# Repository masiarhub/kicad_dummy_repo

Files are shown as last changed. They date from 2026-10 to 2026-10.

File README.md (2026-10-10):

<p align="center" width="100%">
  
</p>

<h1 align="center">Board Name</h1>

<p align="center" width="100%">
  <a href="https://github.com/masiarhub/kicad_dummy_repo/actions/workflows/ci.yaml">
    
  </a>
</p>

<p align="center" width="100%">
    
</p>

***

<p align="center">
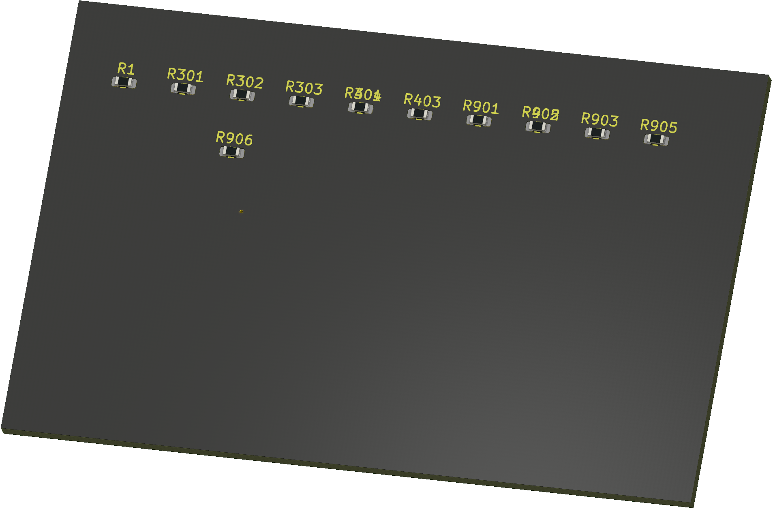
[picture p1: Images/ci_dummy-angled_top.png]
3D Top Angled
  
&nbsp; &nbsp; &nbsp; &nbsp;
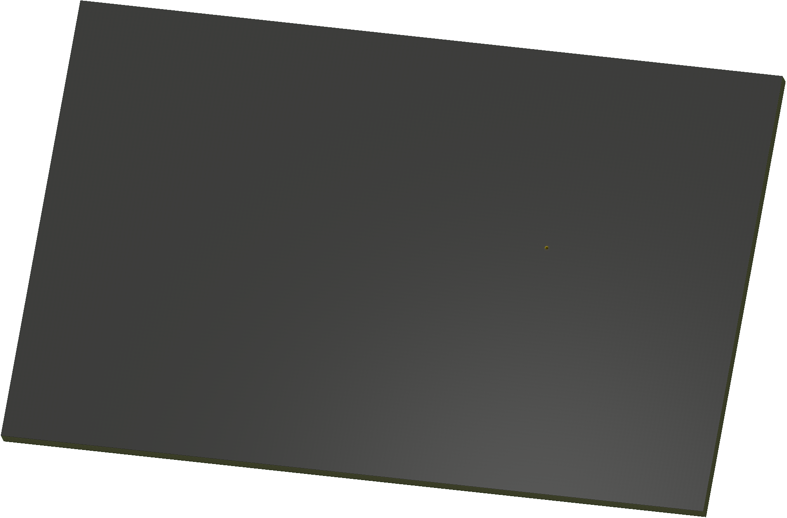
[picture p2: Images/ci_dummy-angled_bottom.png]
3D Bottom Angled
  
</p>

***

## SPECIFICATIONS

| Parameter | Value | 
| --- | --- |
| Dimensions | 70.0 × 45.0 mm |

***

## DIRECTORY STRUCTURE

    .
    ├─ Computations       # Misc calculations
    ├─ HTML               # HTML files for generated webpage
    ├─ Images             # Pictures and renders
    │
    ├─ kibot_resources    # External resources for KiBot
    │  ├─ colors          # Color theme for KiCad
    │  ├─ fonts           # Fonts used in the project
    │  ├─ scripts         # External scripts used with KiBot
    │  └─ templates       # Templates for KiBot generated reports
    │
    ├─ kibot_yaml         # KiBot YAML config files
    ├─ KiRI               # KiRI (PCB diff viewer) files
    │
    ├─ lib                # KiCad footprint and symbol libraries
    │  ├─ 3d_models       # Component 3D models
    │  ├─ lib_fp          # Footprint libraries
    │  └─ lib_sym         # Symbol libraries
    │
    ├─ Logos              # Logos
    │
    ├─ Manufacturing      # Assembly and fabrication documents
    │  ├─ Assembly        # Assembly documents (BoM, pos, notes)
    │  │
    │  └─ Fabrication     # Fabrication documents (ZIP, notes)
    │     ├─ Drill Tables # CSV drill tables
    │     └─ Gerbers      # Gerbers
    │
    ├─ Report             # Reports for ERC/DRC
    ├─ Schematic          # PDF of schematic
    ├─ Templates          # Title block templates
    ├─ Testing
    │  └─ Testpoints      # Testpoints tables      
    │
    └─ Variants           # Outputs for assembly variants

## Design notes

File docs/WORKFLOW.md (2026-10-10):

# Team workflow: KiCad 9 + Git + KiBot CI

## Branch model

```
main      ●───────────────────────●  tag 1.0.0 → release
           \                     /
dev         ●──●─────●─────●────●   integration; CI commits "Update Outputs"
                \   /       \  /
feature/a        ●─●         \/      owner: Alice  (Section A sheet only)
feature/b         ●──●──●───●        owner: Bob    (Section B sheet only)
```

| Branch | Who edits what | CI on push | Pull after CI? |
|---|---|---|---|
| `feature/<name>` | **one** owner, only the files listed for `<name>` in `.github/sheet-ownership.conf` | ownership guard, ERC, schematic PDF as downloadable artifact | **No** (CI commits nothing) |
| `dev` | integrator: root/parent sheets, `.kicad_pro`, net classes, new sheets | full KiBot outputs, committed back | **Yes**, before your next push to dev |
| `main` | nobody directly; PR from dev, then tag | release outputs | yes |

## Why this keeps merge conflicts down

* Every KiCad sheet is its own `.kicad_sch` file. If each branch only touches its own sheet file, Git merges branches without conflicts. The guard enforces this.
* Generated files (PDFs, gerbers, README) are only committed on `dev`/`main`. Feature branches never contain them, so two features can't conflict on binary PDFs. The guard rejects generated files (and CI config in `.github/`, `kibot_yaml/`, `kibot_resources/`) on feature branches.
* The guard reads `sheet-ownership.conf` from `dev`, so editing it on a feature branch has no effect: ownership changes go through the integrator.
* Nobody edits `CHANGELOG.md` on a feature branch. Each change adds its own new file `changelog.d/<feature>-<topic>.md` (see `changelog.d/README.md`), so parallel PRs never touch the same file. The release tag job moves all fragments into `CHANGELOG.md`.
* The `.kicad_pro`, root sheet, parent sheets (which hold the sheet symbols and sheet pins) and the `.kicad_pcb` are shared. Only the integrator changes them, on `dev`.
* `.kicad_prl` (your personal view state) is git-ignored.

## One-time setup (Ubuntu 24.04)

```bash
sudo add-apt-repository ppa:kicad/kicad-9.0-releases
sudo apt update && sudo apt install kicad git
git config --global user.name  "Your Name"
git config --global user.email "you@example.org"
git config --global pull.rebase false     # pull = merge (simplest for KiCad files)
git clone git@github.com:<org>/<project>.git && cd <project>
mkdir -p ~/.local/share/fonts && cp -i kibot_resources/fonts/*.ttf ~/.local/share/fonts/ && fc-cache
cp -i kibot_resources/colors/Altium_Theme.json ~/.config/kicad/9.0/colors/
```

## One "instance" on your feature branch

```bash
# 0. KiCad closed!
git switch feature/power-gen
git pull                                  # get your own latest state
git merge origin/dev                      # optional: pick up integrated work (do it at least weekly)

# 1. change: open the project in KiCad, edit ONLY your sheet, save, CLOSE KiCad
# 2. stage: add your files by name, never "git add -A"
git status
git add "Power - Generation.kicad_sch"
#    changelog: a NEW file per change, never CHANGELOG.md itself
printf '### Added\n- 5V buck stage\n' > changelog.d/power-gen-buck.md
git add changelog.d/power-gen-buck.md
# 3. commit
git commit -m "power-gen: add 5V buck stage"
# 4. push
git push
# 5. check: GitHub → Actions → your run. Green = guard + ERC ok.
#    Download the "schematic-check-N" artifact for the PDF and ERC report.
#    Nothing to pull back on a feature branch.
```

## Rules inside KiCad

1. **Close KiCad before any `git pull / merge / switch`.** KiCad does not reload files changed on disk, and saving afterwards silently overwrites what you pulled.
2. **Edit only your sheet.** Do not move or edit sheet symbols or sheet pins in the parent sheet; ask the integrator.
3. **Annotate: scope "Current sheet only"**, numbering "first free after sheet number × 100" (Alice's sheet 3 gives R301, R302 …). Never "Annotate entire schematic" on a feature branch.
4. **Hierarchical labels** are yours (child sheet). The matching **sheet pins** are the integrator's (parent sheet, "Sync Sheet Pins" on dev after your PR is merged).
5. If KiCad shows `.kicad_pro` or `.kicad_pcb` as modified in `git status`, **don't commit them**: `git restore <file>`.
6. Project symbol libraries: one `.kicad_sym` per feature (`lib/lib_sym/power_gen.kicad_sym`), listed in the mapping file. Footprints in `*.pretty/` are one file each and never conflict.

## Getting your work into dev

1. Open a PR `feature/<name>` → `dev`.
2. Checks: *Sheet ownership guard* and *Schematic check* must be green.
3. Merge with **"Create a merge commit"** (not squash: feature branches live long, and squash makes the next PR from the same branch conflict).
4. CI on dev regenerates all outputs (~ minutes). Then everybody: `git switch dev && git pull`.

## Integrator tasks (on dev, KiCad closed for everyone else on dev)

* **New feature:** create the empty sheet + sheet symbol in the parent, add `name = file` to `.github/sheet-ownership.conf` (and CODEOWNERS), push to dev, then `git switch -c feature/<name> origin/dev && git push -u origin feature/<name>`.
* **Interface change:** after a feature PR adds hierarchical labels, sync the sheet pins in the parent sheet on dev and wire them.
* **Project settings** (net classes, ERC severities, text variables): `.kicad_pro` changes on dev only.
* **PCB:** one layout person at a time, either on dev or on `feature/layout` (mapping `layout = *.kicad_pcb`). After merging dev: *Tools → Update PCB from Schematic*.

## "Only one person per sheet at a time"

Git cannot lock text files. We use:

* the branch owner: the GitHub issue for the feature is **assigned** to whoever currently holds it;
* handoff = holder pushes, waits for green CI, reassigns the issue; the new holder pulls;
* the ownership guard (blocks edits of other people's sheets) and CODEOWNERS review on PRs into dev.

## Releasing (unchanged from the template)

PR `dev` → `main`, then `git switch main && git pull && git tag 1.0.0 && git push origin 1.0.0`, then `git switch dev && git merge main`.

CI rejects a tag that does not point at a commit on `main`. If that happens, delete the tag (`git tag -d 1.0.0 && git push origin :refs/tags/1.0.0`) and tag `main`.

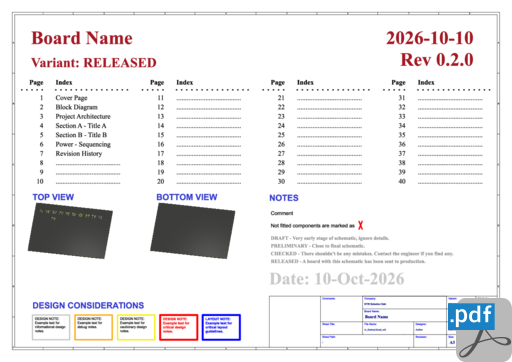
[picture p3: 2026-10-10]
HTML/images/cat_pdf_schematic_ci_dummy-schematic.png

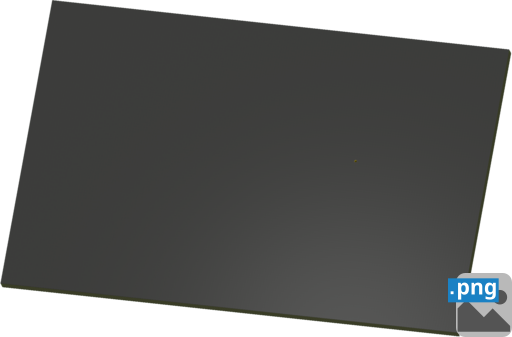
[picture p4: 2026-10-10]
HTML/images/cat_png_3d_viewer_angled_bottom_ci_dummy-angled_bottom.png

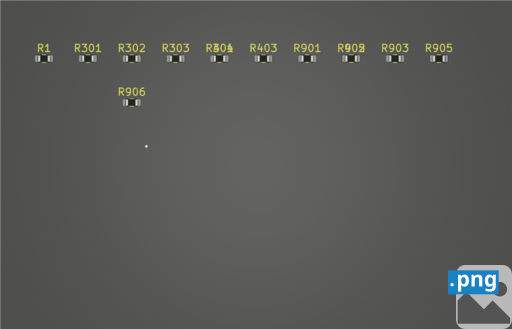
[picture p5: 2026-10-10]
HTML/images/cat_png_3d_viewer_top_ci_dummy-top.png

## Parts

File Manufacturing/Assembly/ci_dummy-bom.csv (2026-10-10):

Row | Quantity Per PCB | References | Value | Datasheet | Footprint | Description | Manufacturer | Manufacturer Part Number | Supplier Part Number
1 | 1 | R405 | 150 | ~ | R_0603_1608Metric
2 | 1 | R903 | 1k | ~ | R_0603_1608Metric
3 | 1 | R1 | 2k2 | ~ | R_0603_1608Metric
4 | 1 | R403 | 3k3 | ~ | R_0603_1608Metric
5 | 1 | R401 | 4k7 | ~ | R_0603_1608Metric
6 | 2 | R301 R905 | 10k | ~ | R_0603_1608Metric
7 | 1 | R302 | 22k | ~ | R_0603_1608Metric
8 | 1 | R906 | 33k | ~ | R_0603_1608Metric
9 | 1 | R303 | 47k | ~ | R_0603_1608Metric
10 | 1 | R304 | 68k | ~ | R_0603_1608Metric
11 | 2 | R901 R902 | 100k | ~ | R_0603_1608Metric

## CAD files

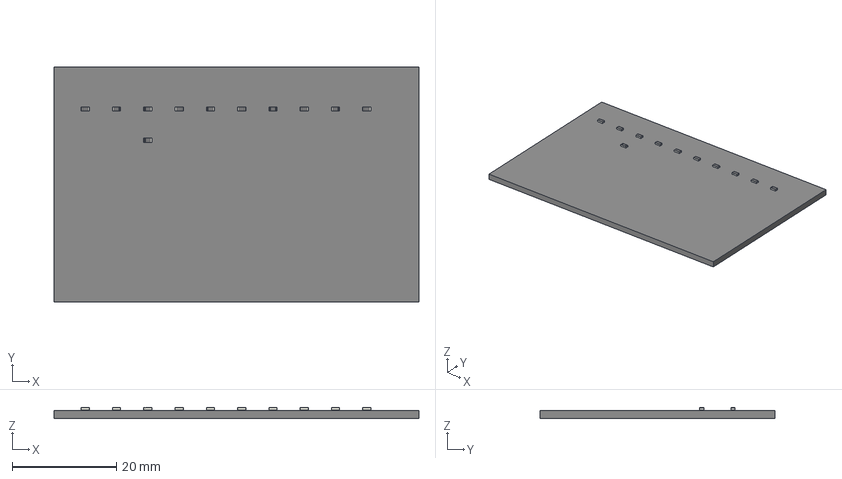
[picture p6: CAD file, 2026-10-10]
3D/ci_dummy.step
70.0 x 45.0 x 2.05 mm
R_0603_1608Metric x 13
kibot_hq2c7fhe_PCB

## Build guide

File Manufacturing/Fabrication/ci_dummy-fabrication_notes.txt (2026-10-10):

FABRICATION NOTES (UNLESS OTHERWISE SPECIFIED)

1)	FABRICATE PER IPC-6012A CLASS 2.

2)	OUTLINE DEFINED IN SEPARATE GERBER FILE WITH
	"Edge_Cuts.GBR" SUFFIX.

	DIMENSIONS OF CIRCUMSCRIBED RECTANGLE SHOWN ON THIS
	DRAWING FOR REFERENCE ONLY.

3)	SEE SEPARATE DRILL FILES WITH ".DRL" SUFFIX 
	FOR HOLE LOCATIONS.

	SELECTED HOLE LOCATIONS SHOWN ON THIS DRAWING 
	FOR REFERENCE ONLY.

4)	SURFACE FINISH: IMMERSION GOLD

5)	SOLDERMASK ON BOTH SIDES OF THE BOARD SHALL 
	BE LPI, COLOR BLACK.

6)	SILKSCREEN LEGEND TO BE APPLIED PER LAYER 
	STACKUP USING YELLOW NON-CONDUCTIVE EPOXY INK.

7)	ALL VIAS ARE TENTED ON BOTH SIDES UNLESS 
	SOLDERMASK IS OPENED IN THE GERBER FILES.

8)	VENDOR SHOULD FOLLOW RoHS COMPLIANT PROCESS 
	AND Pb FREE FOR MANUFACTURING

9)	PCB MATERIAL REQUIREMENTS:

	A.	FLAMMABILITY RATING MUST MEET OR EXCEED 
		UL94V-0 REQUIREMENTS.
	B.	Tg 170 C OR EQUIVALENT.
	C.	EQUIVALENT MATERIAL SHALL BE RoHS COMPLIANT, 
		HALOGEN FREE AND APPROVED BY ETH ROBOTICS CLUB.

10)	DESIGN GEOMETRY MINIMUM FEATURE SIZES:

	BOARD SIZE				70.000 × 45.000 mm
	BOARD THICKNESS		1.660 mm
	TRACE WIDTH			N/A mm
	TRACE TO TRACE		0.200 mm
	MIN. HOLE (PTH)			0.300 mm
	MIN. HOLE (NPTH)		N/A mm
	ANNULAR RING			0.150 mm
	COPPER TO HOLE		0.254 mm
	COPPER TO EDGE		0.250 mm
	HOLE TO HOLE			0.254 mm

11)	REFER TO IMPEDANCE TABLE FOR IMPEDANCE CONTROL REQUIREMENTS.

12)	CONFIRM SPACE WIDTHS AND SPACINGS.

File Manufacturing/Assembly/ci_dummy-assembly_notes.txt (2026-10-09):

ASSEMBLY NOTES (UNLESS OTHERWISE SPECIFIED)

1)	DO NOT POPULATE PARTS ARE MARKED WITH A RED CROSS.

2)	DO NOT POPULATE PARTS ARE NOT PRESENT IN THE BOM.

3)	IF CONFLICTING INFORMATION IS FOUND BETWEEN THE ASSEMBLY
	FILE AND BOM, BOM SHOULD BE USED AS THE MAIN SOURCE.

4)	CONFORMAL COATING IS NOT REQUIRED.

5)	DOT IDENTIFIES PIN #1 LOCATION AND DEVICE ORIENTATION
	WHEN VIEWED FROM THE TOP.

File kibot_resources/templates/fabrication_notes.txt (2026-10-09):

FABRICATION NOTES (UNLESS OTHERWISE SPECIFIED)

1)	FABRICATE PER IPC-6012A CLASS 2.

2)	OUTLINE DEFINED IN SEPARATE GERBER FILE WITH
	"Edge_Cuts.GBR" SUFFIX.

	DIMENSIONS OF CIRCUMSCRIBED RECTANGLE SHOWN ON THIS
	DRAWING FOR REFERENCE ONLY.

3)	SEE SEPARATE DRILL FILES WITH ".DRL" SUFFIX 
	FOR HOLE LOCATIONS.

	SELECTED HOLE LOCATIONS SHOWN ON THIS DRAWING 
	FOR REFERENCE ONLY.

4)	SURFACE FINISH: ${pcb_finish_cap}

5)	SOLDERMASK ON BOTH SIDES OF THE BOARD SHALL 
	BE LPI, COLOR ${solder_mask_color_text_cap}.

6)	SILKSCREEN LEGEND TO BE APPLIED PER LAYER 
	STACKUP USING ${silk_screen_color_text_cap} NON-CONDUCTIVE EPOXY INK.

7)	ALL VIAS ARE TENTED ON BOTH SIDES UNLESS 
	SOLDERMASK IS OPENED IN THE GERBER FILES.

8)	VENDOR SHOULD FOLLOW RoHS COMPLIANT PROCESS 
	AND Pb FREE FOR MANUFACTURING

9)	PCB MATERIAL REQUIREMENTS:

	A.	FLAMMABILITY RATING MUST MEET OR EXCEED 
		UL94V-0 REQUIREMENTS.
	B.	Tg 170 C OR EQUIVALENT.
	C.	EQUIVALENT MATERIAL SHALL BE RoHS COMPLIANT, 
		HALOGEN FREE AND APPROVED BY ${COMPANY_cap}.

10)	DESIGN GEOMETRY MINIMUM FEATURE SIZES:

	BOARD SIZE				${bb_w_mm} × ${bb_h_mm} mm
	BOARD THICKNESS		${thickness_mm} mm
	TRACE WIDTH			${track_mm} mm
	TRACE TO TRACE		${clearance_mm} mm
	MIN. HOLE (PTH)			${drill_pth_real_mm} mm
	MIN. HOLE (NPTH)		${drill_npth_real_mm} mm
	ANNULAR RING			${oar_mm} mm
	COPPER TO HOLE		${c2h_mm} mm
	COPPER TO EDGE		${c2e_mm} mm
	HOLE TO HOLE			${h2h_mm} mm
#?stackup and impedance_controlled

#?stackup and impedance_controlled
11)	REFER TO IMPEDANCE TABLE FOR IMPEDANCE CONTROL REQUIREMENTS.
#?stackup and impedance_controlled

#?stackup and impedance_controlled
12)	CONFIRM SPACE WIDTHS AND SPACINGS.

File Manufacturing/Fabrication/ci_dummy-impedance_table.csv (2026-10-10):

Transmission Line | Impedance [ohms] | Tolerance [ohms] | Layer | Trace Width [mm] | Gap [mm] | Ref. Layers
Edge-Coupled Coated Microstrip | 100 | ±10 % | L1 | 0.2032 | 0.28 | L2

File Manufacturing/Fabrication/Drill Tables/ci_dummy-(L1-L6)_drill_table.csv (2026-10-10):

Count | Hole Size | Plated | Hole Shape | Drill Layer Pair | Hole Type
1 | 0.30mm (11.81mils) | PTH | Round | L1 (Sig, PWR) - L6 (Sig, PWR) | Via
Total 1

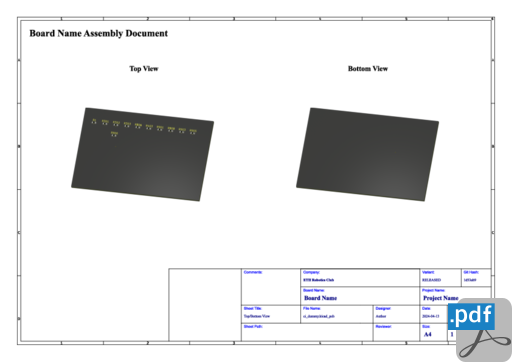
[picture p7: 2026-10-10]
HTML/images/cat_pdf_assembly_ci_dummy-assembly.png

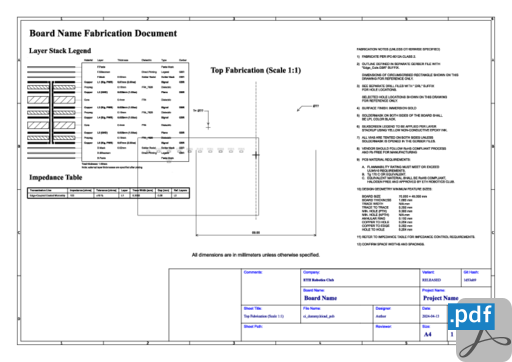
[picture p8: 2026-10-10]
HTML/images/cat_pdf_fabrication_ci_dummy-fabrication.png

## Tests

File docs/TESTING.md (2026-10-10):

# Testing the workflow (Ubuntu 24.04)

Use the template's own schematic as the dummy project: it already has
hierarchical sub-sheets (`Section A`, `Section B` under `Project Architecture`,
`Power - Sequencing` under the root), and `sheet-ownership.conf` maps them.

## 0. Tools

```bash
sudo add-apt-repository ppa:kicad/kicad-9.0-releases
sudo apt update && sudo apt install -y kicad git shellcheck
# GitHub CLI (optional, handy for watching runs)
sudo apt install -y gh && gh auth login
# actionlint (workflow linter)
curl -sSL https://github.com/rhysd/actionlint/releases/download/v1.7.7/actionlint_1.7.7_linux_amd64.tar.gz \
  | tar xz actionlint && sudo mv actionlint /usr/local/bin/
```

## 1. Static checks (seconds, before every push of CI changes)

```bash
actionlint .github/workflows/ci.yaml
shellcheck .github/scripts/check_sheet_ownership.sh
FEATURE_BRANCH=feature/section-a bash .github/scripts/check_sheet_ownership.sh   # on a feature branch
```

## 2. Dummy project from the adjusted template

Don't test in a real project repo. Make a throw-away project from this
template branch and give it its own repo in the org (public = unlimited
Actions minutes and branch rulesets on the Free plan).

```bash
# 2a. Install the adjusted template into KiCad 9's user template folder
mkdir -p ~/.local/share/kicad/9.0/template && cd ~/.local/share/kicad/9.0/template
git clone -b ci/multi-user-workflow git@github.com:ETHRoboticsClub/KDT_Hierarchical_KiBot.git
mkdir -p ~/.local/share/fonts && cp -i KDT_Hierarchical_KiBot/kibot_resources/fonts/*.ttf ~/.local/share/fonts/ && fc-cache
mkdir -p ~/.config/kicad/9.0/colors && cp -i KDT_Hierarchical_KiBot/kibot_resources/colors/Altium_Theme.json ~/.config/kicad/9.0/colors/
```

2b. In KiCad: **File → New Project From Template → KDT_Hierarchical_KiBot**,
name it e.g. `ci_dummy`, in `~/ci-test/ci_dummy/`. Close KiCad.

2c. KiCad does **not** copy hidden files from a template on Linux. Copy them
yourself, then make it a repo with `main` and `dev`:

```bash
T=~/.local/share/kicad/9.0/template/KDT_Hierarchical_KiBot
cd ~/ci-test/ci_dummy
cp -r "$T/.github" "$T/.gitignore" "$T/.gitattributes" .
cp -rn "$T/docs" .                       # in case KiCad skipped it
ls "Section A - Title A.kicad_sch" "Section B - TItle B.kicad_sch"   # sub-sheets keep their names
rm -rf .git                               # in case KiCad copied the template's history
git init -b main && git add -A && git commit -m "Dummy project from template"
git switch -c dev
# create the empty repo ETHRoboticsClub/kicad-ci-sandbox on GitHub first (no README), then:
git remote add origin git@github.com:ETHRoboticsClub/kicad-ci-sandbox.git
git push -u origin main dev
```

What to check after renaming:

* `.github/sheet-ownership.conf`: the three sub-sheet entries still match (KiCad only renames the root files to `ci_dummy.*`). If you add your own sheets, add a line per feature.
* `.github/CODEOWNERS`: optional for the test; rules are commented out.
* `kibot_yaml/kibot_main.yaml`: `GIT_URL` points to the template repo; set it to the sandbox URL (it only appears in the generated docs).

GitHub settings of the sandbox:

* **Actions → General → Workflow permissions:** "Read and write". If the org forbids it, the dev output commit fails with 403 (T6).
* **Secrets and variables → Actions → Variables:** none needed (defaults: `KIBOT_VARIANT=DRAFT`, `ERC_BLOCKING=false`, `SHEET_GUARD_MODE=fail`).
* **Rules → Rulesets** (later, T8): ruleset on `dev`: require PR, required checks *Sheet ownership guard* and *Schematic check (ERC + PDF artifact)*.

The first push of `dev` already runs CI: wait for the "Update Outputs" commit
before cloning (step 3).

## 3. Simulate two users on one machine

```bash
cd ~/ci-test
git clone git@github.com:ETHRoboticsClub/kicad-ci-sandbox.git alice
git clone git@github.com:ETHRoboticsClub/kicad-ci-sandbox.git bob
git -C alice config user.name Alice && git -C alice config user.email alice@example.org
git -C bob   config user.name Bob   && git -C bob   config user.email bob@example.org
git -C alice switch -c feature/section-a origin/dev && git -C alice push -u origin feature/section-a
git -C bob   switch -c feature/section-b origin/dev && git -C bob   push -u origin feature/section-b
```

Open `alice/ci_dummy.kicad_pro` in KiCad for Alice's edits and
`bob/ci_dummy.kicad_pro` for Bob's. Close KiCad between users. Leave the
original `~/ci-test/ci_dummy` folder alone after step 2 (or delete it), so you
don't push from three places.

## 4. Test cases

| # | Do | Expect |
|---|---|---|
| T1 | Alice: add a resistor in *Section A*, annotate current sheet only, commit just that file, push | guard ✅, ERC step runs, artifact `schematic-check-N` contains a schematic PDF showing the resistor. **No** commit from CI on `feature/section-a` |
| T2 | Bob (in parallel): same in *Section B*, push | same as T1 |
| T3 | Both open PRs into dev, merge Alice's, then Bob's | Bob's PR merges **without conflicts**. After each merge, a dev run commits "Update Outputs" |
| T4 | Alice: edit *Section B* too, push | guard ❌, annotation on the file name in the run summary |
| T5 | Alice: change a net class (touches `.kicad_pro`), push | guard ❌ (shared file) |
| T6 | After T3: Bob pushes to dev **without** pulling | push rejected (non-fast-forward). `git pull` merges cleanly (only outputs changed), push works |
| T7 | Push two commits to dev 30 s apart | second run waits (concurrency); first run logs "Outputs not pushed … branch moved"; only one "Update Outputs" commit lands |
| T8 | Enable the dev ruleset (require PR) | **Expected failure**: CI can't push "Update Outputs" to dev. Fix: add the bypass actor (or deploy key) for CI, or require PRs only on main. Re-run T3 |
| T9 | Alice and Bob both edit *Project Architecture* (parent sheet) on dev | real Git conflict: demonstrates why parent sheets belong to the integrator |
| T10 | Both annotate with "entire schematic" on their branches, merge | Git merges, ERC on dev reports duplicate references: demonstrates the annotation rule |
| T11 | Set `ERC_BLOCKING=true`, push a feature with an unconnected pin | Schematic check ❌ |
| T12 | PR dev → main, merge, `git tag 0.1.0 && git push origin 0.1.0` | release with assets; `CHANGELOG.md` gets a `0.1.0` section containing all `changelog.d/` fragments, which are deleted on main; then `git switch dev && git merge origin/main` |
| T13 | Alice: add `section-a = *.kicad_sch` to `sheet-ownership.conf` on her branch and edit *Section B*, push | guard ❌ for *Section B* and for the conf file (mapping is read from dev) |
| T14 | Alice: run KiBot locally, commit `Schematic/*.pdf`, push | guard ❌ "generated by CI on dev" |
| T15 | Alice and Bob each add a fragment (`changelog.d/section-a-adc.md`, `changelog.d/section-b-can.md`) on their branches, merge both PRs on GitHub. Then add a fragment without a `###` heading | no conflict; at the next release tag both entries are in `CHANGELOG.md` and the release notes. The broken fragment fails the guard job with an annotation |
| T16 | Push a schematic change to dev, then within the run push a commit that only changes a `.md` file | second push starts no run; first run rebases "Update Outputs" onto it and pushes |
| T17 | Tag a commit that is on dev but not on main, push the tag | generate_outputs ❌ "Tag not on main", nothing pushed to main, no release |

Pass = T1–T7, T11–T17 behave as expected and you understood T8–T10.

## 5. Optional: run KiBot locally (Docker)

```bash
sudo apt install -y docker.io && sudo usermod -aG docker $USER   # log out/in once
./kibot_resources/scripts/docker_kibot_linux.sh -v 9
# inside the container:
./kibot_launch.sh -v DRAFT
```

Useful to debug KiBot config errors without waiting for Actions. Don't commit
locally generated outputs; CI owns them.

## 6. Moving to the real project

Once this branch is merged into the template's `main`, new projects get
everything via **New Project From Template** (plus the hidden-file copy in
2c). For an existing project, copy `.github/`, `.gitignore`, `.gitattributes`,
`docs/` into its repo on dev, rewrite `sheet-ownership.conf` and `CODEOWNERS`
for your sheets, push, and re-run T1 and T3 once with real people.

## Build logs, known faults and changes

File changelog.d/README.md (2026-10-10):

# Changelog fragments

Don't edit `CHANGELOG.md` on a feature branch. Add a **new** file here instead,
one per change, named `<feature>-<topic>.md` (e.g. `power-gen-buck.md`):

```markdown
### Added
- 5V buck converter (TPS62130), 3 A

### Fixed
- Swapped CAN_H / CAN_L labels
```

Headings: `Added`, `Changed`, `Deprecated`, `Removed`, `Fixed`, `Security`.
Every PR adds a different file, so PRs never conflict here. Don't edit or
delete other people's fragments.

The PR check validates the fragments. When a release tag is pushed, CI moves
all fragments into `CHANGELOG.md` (section of the new version) and deletes
them. Preview locally: `python3 .github/scripts/collect_changelog.py --check`.

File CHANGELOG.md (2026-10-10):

# Changelog

## [Unreleased]

## [0.2.0] - 2026-10-10

### Added

-   Section A: R304 ADC input bias
-   Section B: CAN termination R405

### Fixed

-   Section A: R303 value

## [0.1.0] - 2026-10-10

### Fixed

-   Fixes

### Added

-   Section B: R401 bias resistor
-   Section A: R301-R303 input divider
-   Additions

### Changed

-   Changes

### Removed

-   Deletions

[Unreleased]: https://github.com/masiarhub/kicad_dummy_repo/compare/0.2.0...HEAD

[0.2.0]: https://github.com/masiarhub/kicad_dummy_repo/compare/0.1.0...0.2.0

[0.1.0]: https://github.com/masiarhub/kicad_dummy_repo/compare/0.1.0...0.1.0

[0.1.0]: https://github.com/masiarhub/kicad_dummy_repo/compare/c2824a74ee5e3f6b86e777ef1005d53f781ad9ca...0.1.0

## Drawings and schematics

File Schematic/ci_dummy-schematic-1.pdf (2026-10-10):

2026-10-10

# Variant:RELEASED

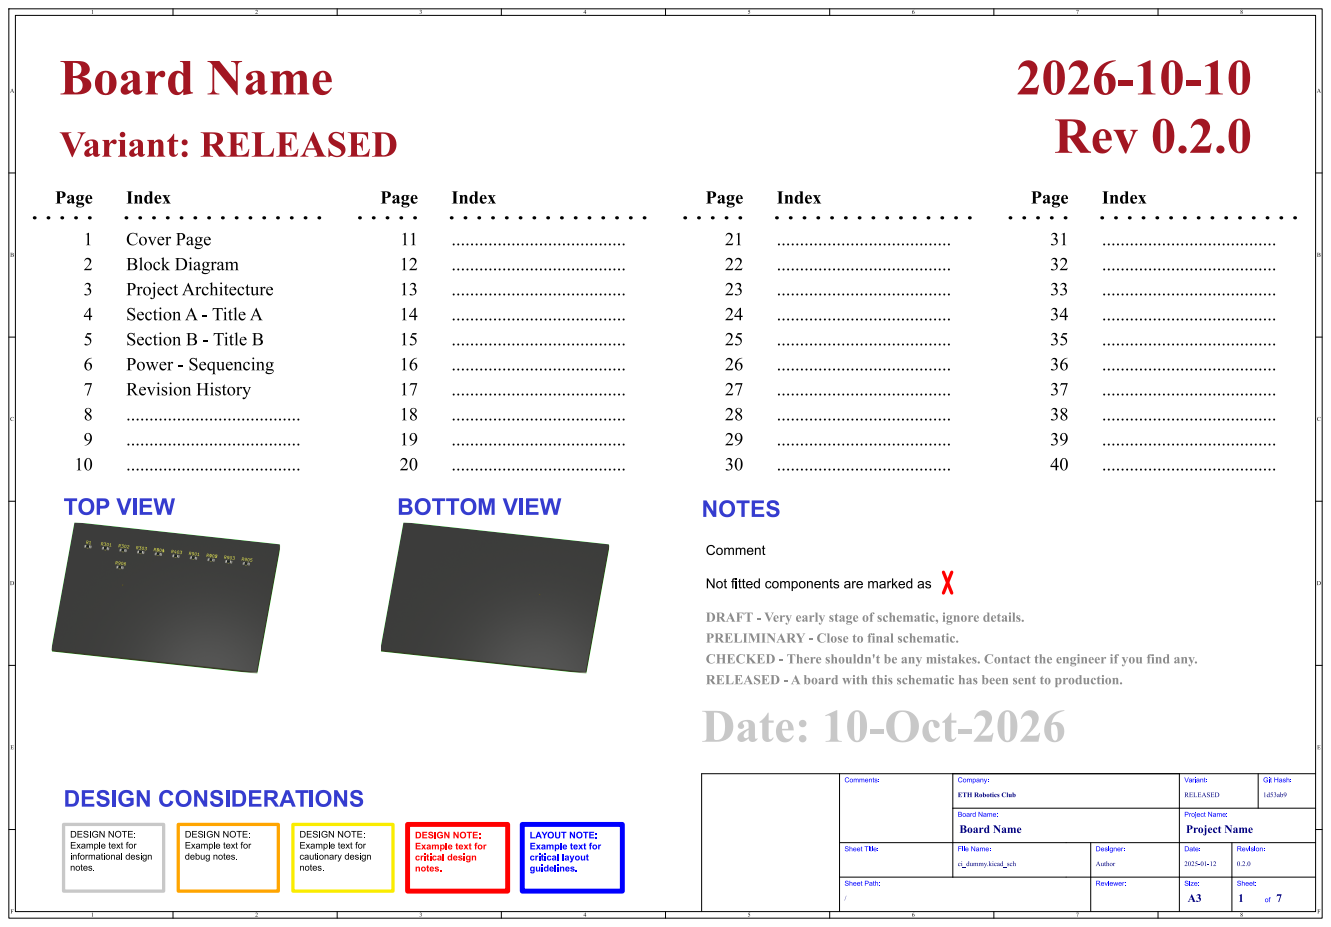
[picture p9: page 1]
Sheet: of 7; Size: A3; ci_dummy.kicad_sch; Author Board Name:; Variant: RELEASED; Company: ETH RoboticsClub BoardName; ProjectName; Sheet Title:; File Name:; /Sheet Path: Comments:; Git Hash: 1d53ab9 ProjectArchitecture; kibot_image_png_3d_viewer_angled_top; LAYOUT NOTE:; kibot_image_png_3d_viewer_angled_bottom; Rev0.2.0; Page; Index; BOTTOM VIEW; DESIGN CONSIDERATIONS; TOP VIEW; SectionA - Title A; ...................................... ProjectArchitecture; Power- Sequencing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

Not fitted components are marked as

DRAFT - Veryearlystageof schematic,ignoredetails.
PRELIMINARY - Closetofinal schematic.
CHECKED - Thereshouldn'tbeanymistakes.Contacttheengineerif youfindany.
RELEASED - A boardwiththisschematichasbeensenttoproduction.

Revision: 0.2.0 Date: Project Name: 2025-01-12 Reviewer: Designer:

DESIGN NOTE:
Example text for
informational design
notes.

debug notes.

cautionary design

critical design

critical layout
guidelines.

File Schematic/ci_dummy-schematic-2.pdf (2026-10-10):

## Page4

# [2] BlockDiagram

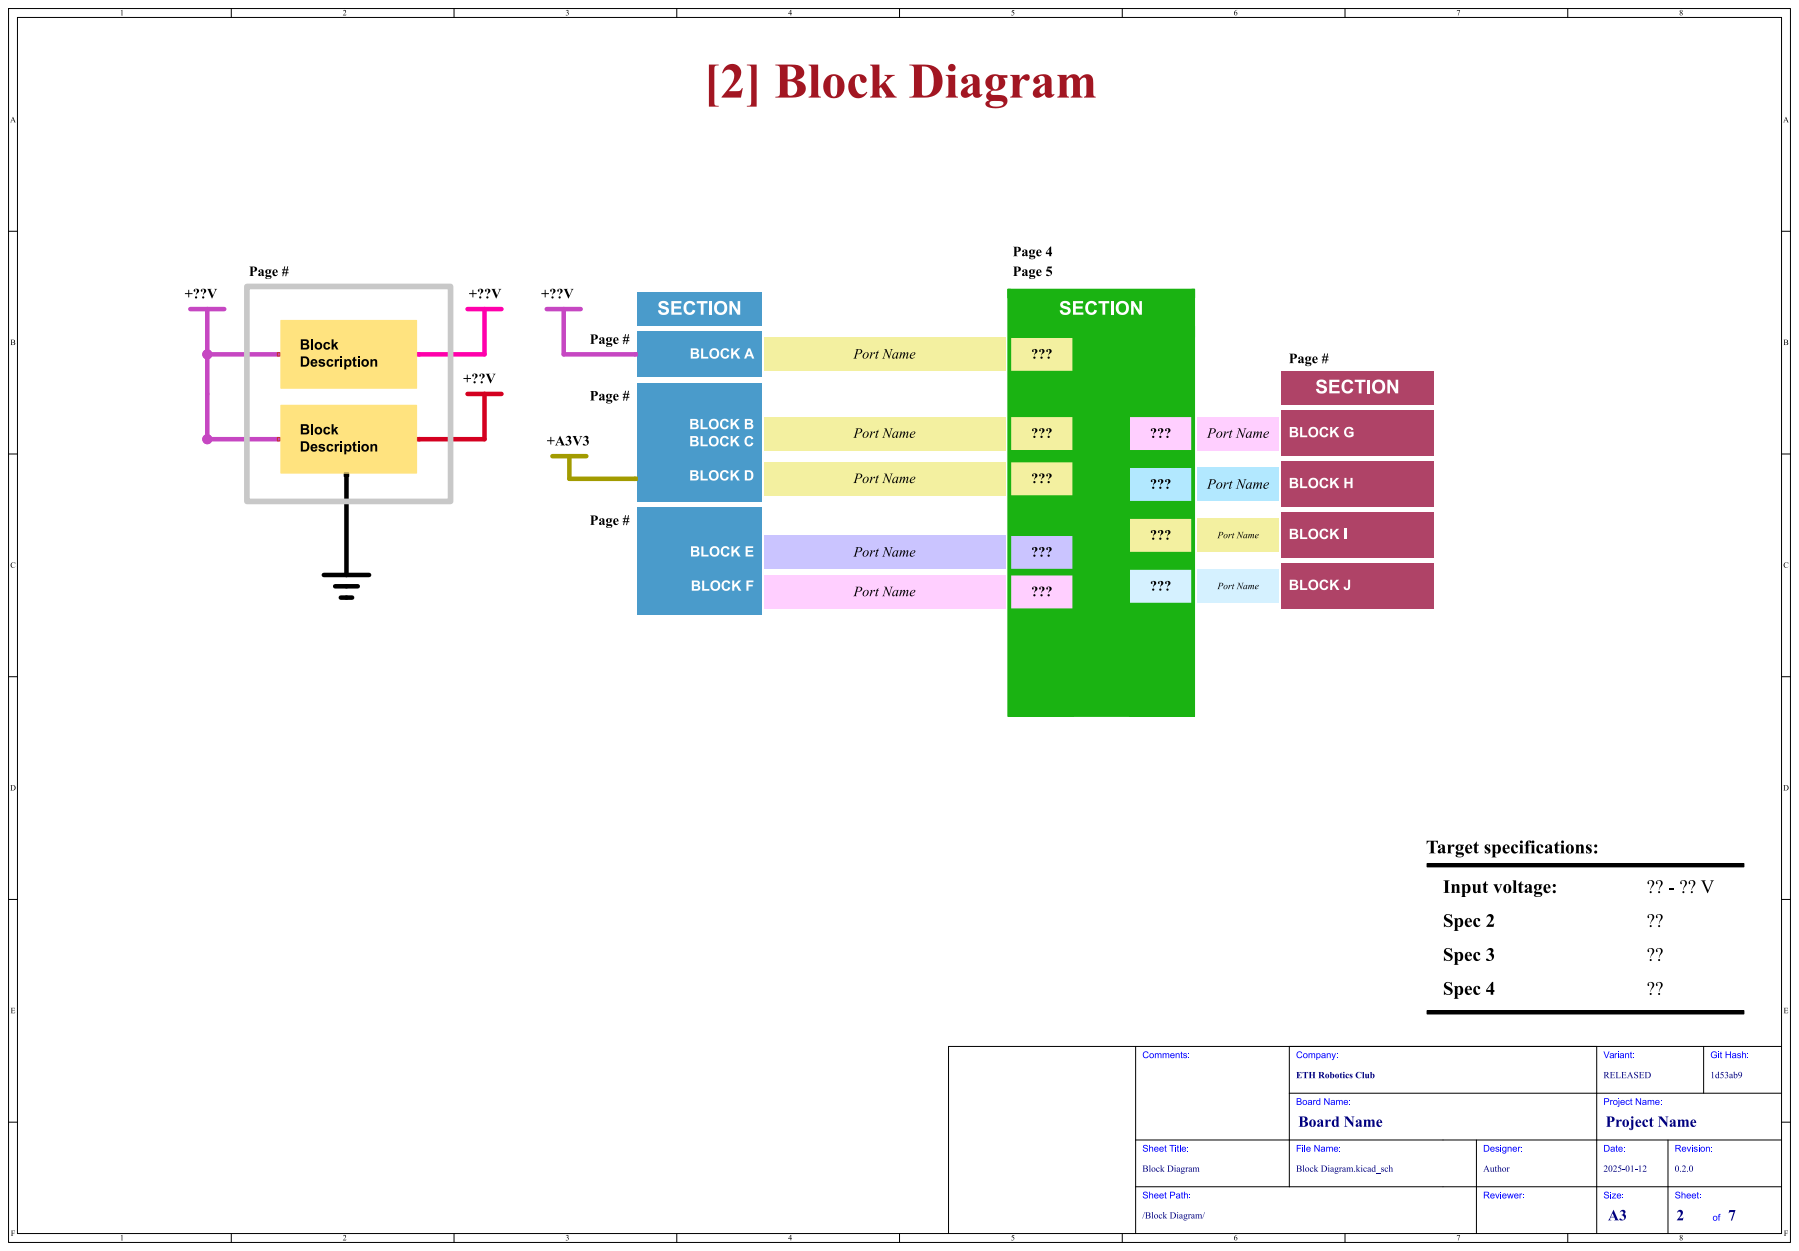
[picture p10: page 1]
Sheet: of 7; Size: A3; Revision: 0.2.0 Date: Project Name: 2025-01-12 Reviewer: Designer: Block Diagram.kicad_sch; Author Board Name:; Variant: RELEASED; Company: ETH RoboticsClub BoardName; ProjectName; Sheet Title:; File Name:; Comments:; Git Hash: 1d53ab9; Page#; Input voltage:; BLOCK J; BLOCK I; BLOCK H; SECTION; BLOCK G; Spec3 Spec4; Spec2; Port Name; Page5; Port Name ???; Targetspecifications:; Block Description; BLOCK B BLOCK C; BLOCK D; BLOCK E; BLOCK F; BLOCK A

Port Name

/Block Diagram/ Sheet Path: Block Diagram

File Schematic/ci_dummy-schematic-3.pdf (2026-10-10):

# File: Section B - TItle B.kicad_sch SectionA - Title A

1k | Description

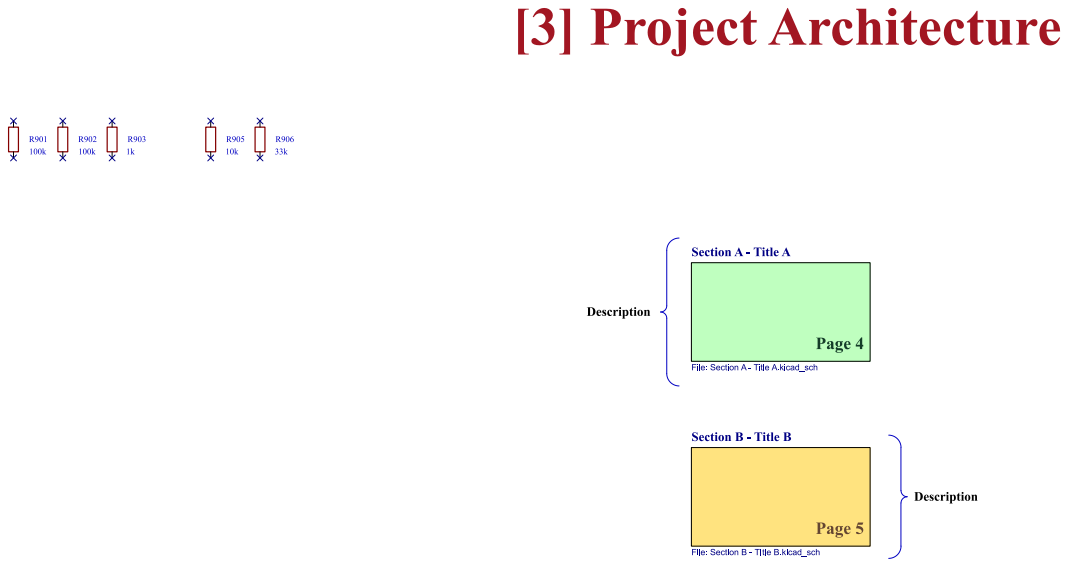
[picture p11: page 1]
Sheet: of 7; Size: A3; ProjectArchitecture.kicad_sch; Author Board Name:; Variant: RELEASED; Company: ETH RoboticsClub BoardName; ProjectName; Sheet Title:; File Name:; /ProjectArchitecture/ Sheet Path: ProjectArchitecture Comments:; Git Hash: 1d53ab9; SectionB - Title B; Description; [3] ProjectArchitecture; Page5; Page4

File: Section A - Title A.kicad_sch R901

Revision: 0.2.0 Date: Project Name: 2025-01-12 Reviewer: Designer:

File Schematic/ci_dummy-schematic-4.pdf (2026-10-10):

# 47k [4] SheetTitle A

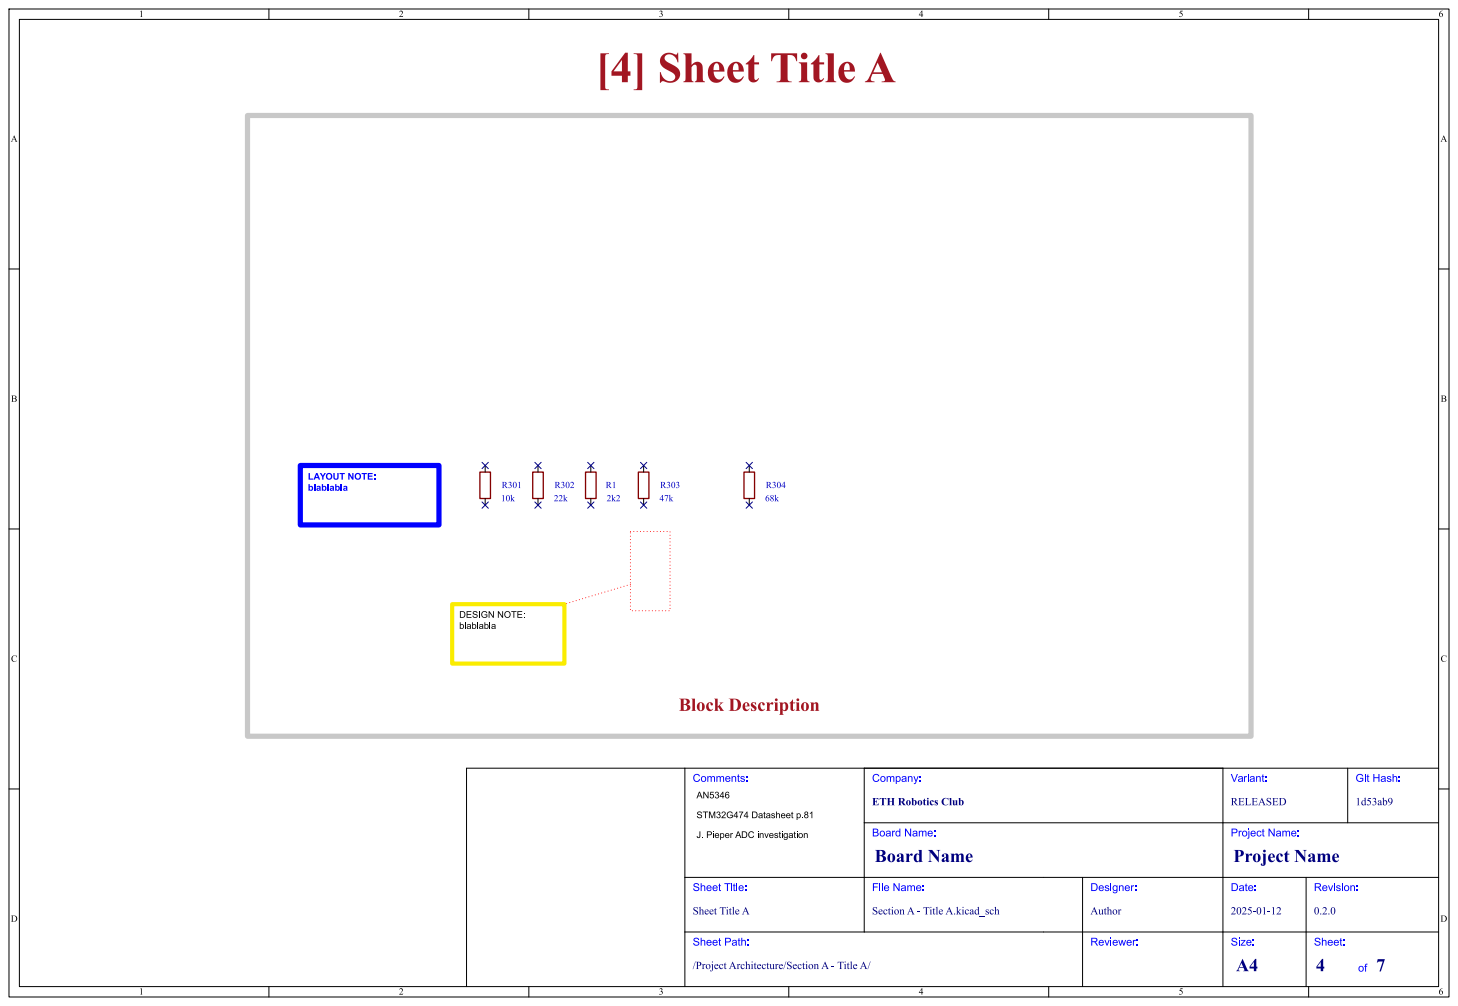
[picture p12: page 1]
Sheet: of 7; Size: A4; Revision: 0.2.0 Date: Project Name: 2025-01-12 Reviewer: Designer: SectionA - Title A.kicad_sch; Author Board Name:; Variant: RELEASED; Company: ETH RoboticsClub BoardName; ProjectName; Sheet Title:; File Name:; /ProjectArchitecture/SectionA - Title A/ Sheet Path: SheetTitle A Comments:; Git Hash: 1d53ab9 R301; LAYOUT NOTE: blablabla; BlockDescription; DESIGN NOTE: blablabla; STM32G474 Datasheet p.81

J. Pieper ADC investigation (https://jpieper.com/2023/07/24/stm32g4-adc-performance-part-2/) AN5346

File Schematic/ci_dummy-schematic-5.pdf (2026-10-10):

# [5] SheetTitle B

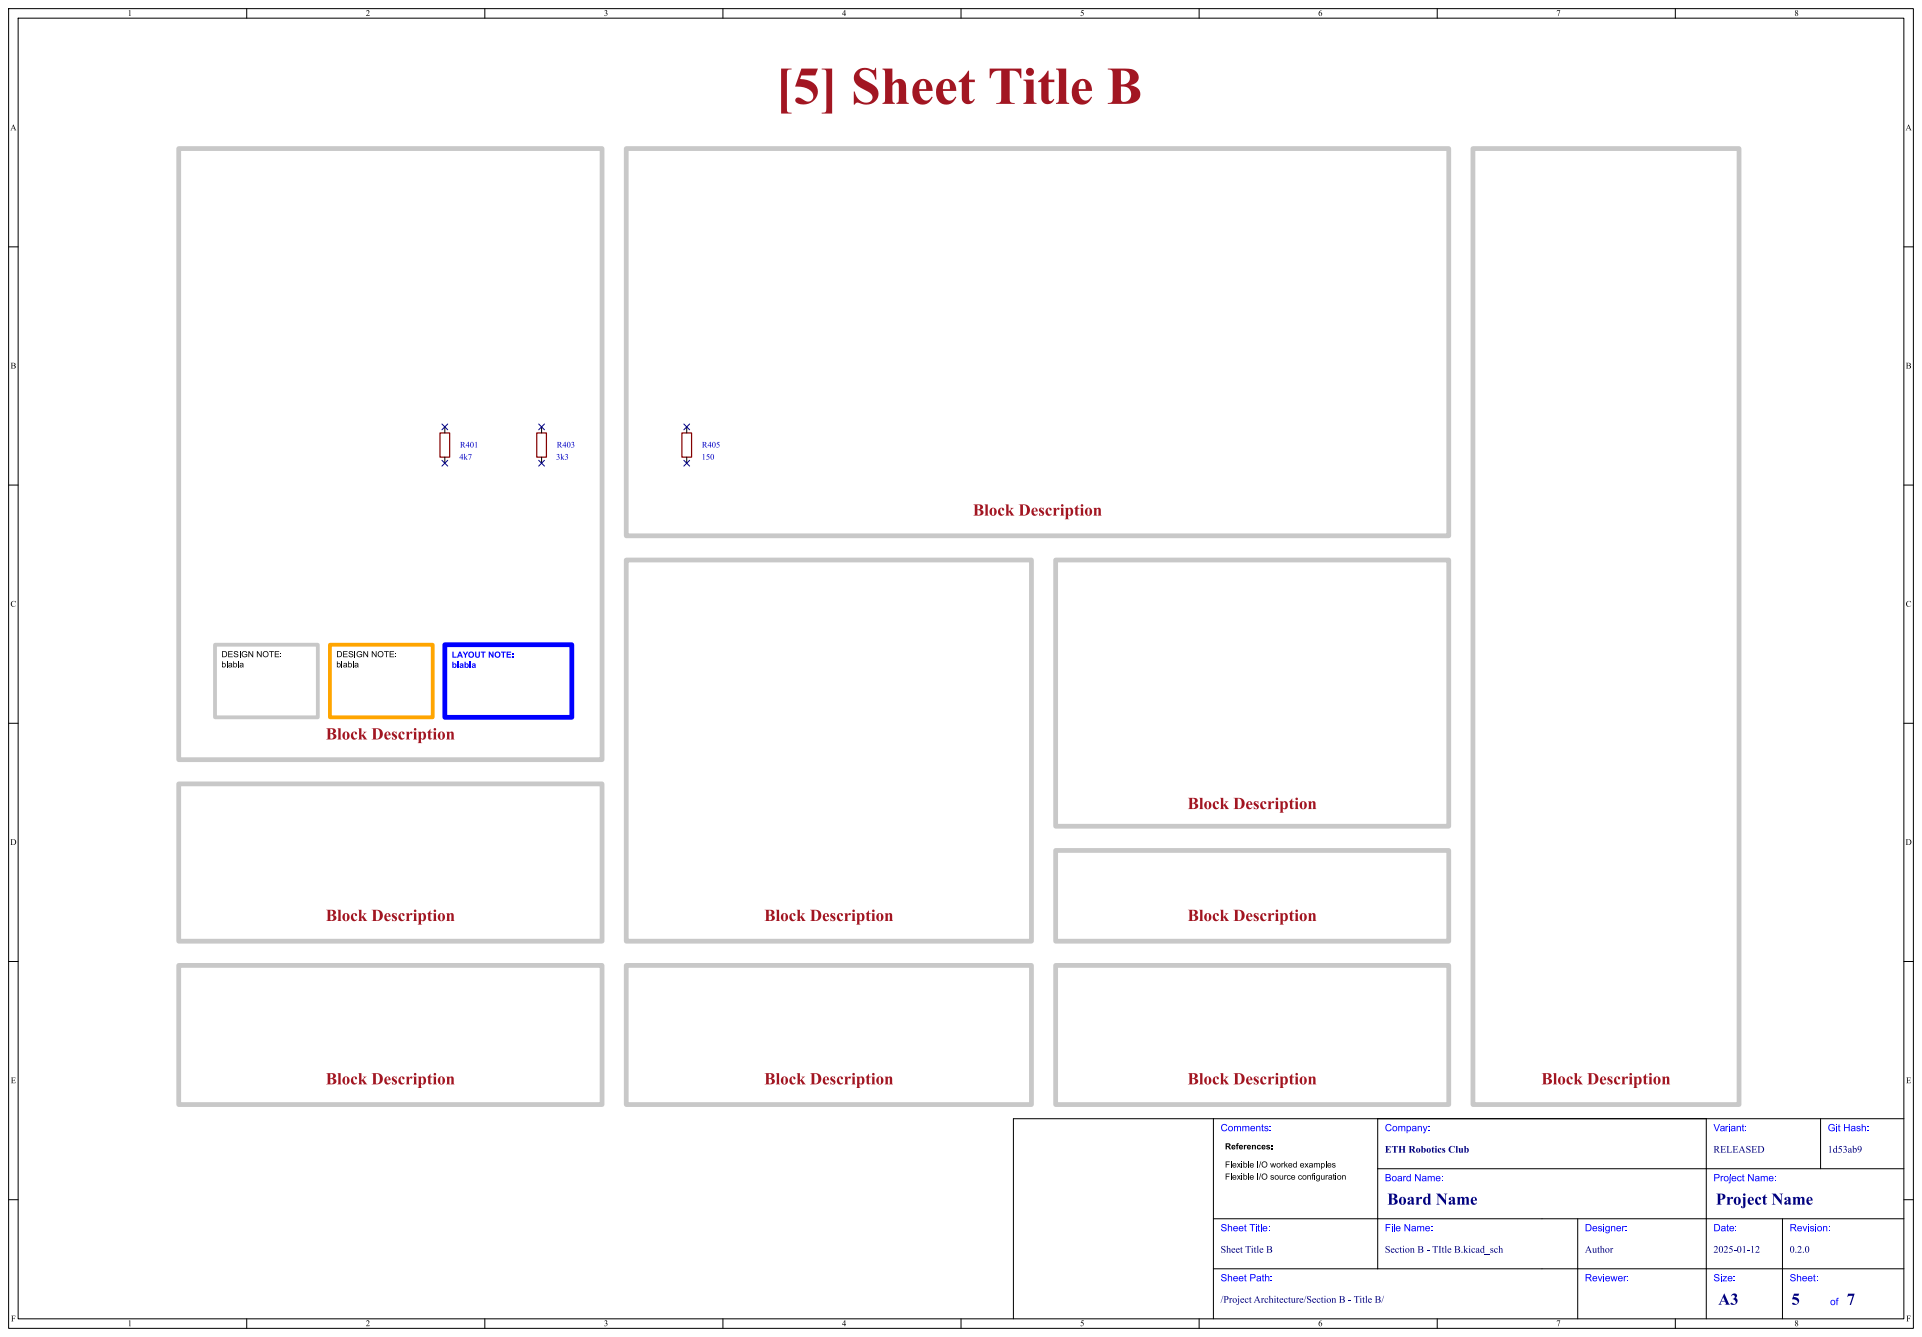
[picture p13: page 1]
Sheet: of 7; Size: A3; Revision: 0.2.0 Date: Project Name: 2025-01-12 Reviewer: Designer: SectionB - TItle B.kicad_sch; Author Board Name:; Variant: RELEASED; Company: ETH RoboticsClub BoardName; ProjectName; Sheet Title:; File Name:; /ProjectArchitecture/SectionB - Title B/ Sheet Path: SheetTitle B Comments:; Git Hash: 1d53ab9; 3k3 DESIGN NOTE: blabla; BlockDescription; DESIGN NOTE: blabla; LAYOUT NOTE: blabla BlockDescription

Flexible I/O source configuration (https://jpieper.com/2022/06/28/flexible-i-o-source-configuration/) References: Flexible I/O worked examples

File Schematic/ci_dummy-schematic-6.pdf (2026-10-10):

## SOURCE LEVEL

# [6] Power- Sequencing

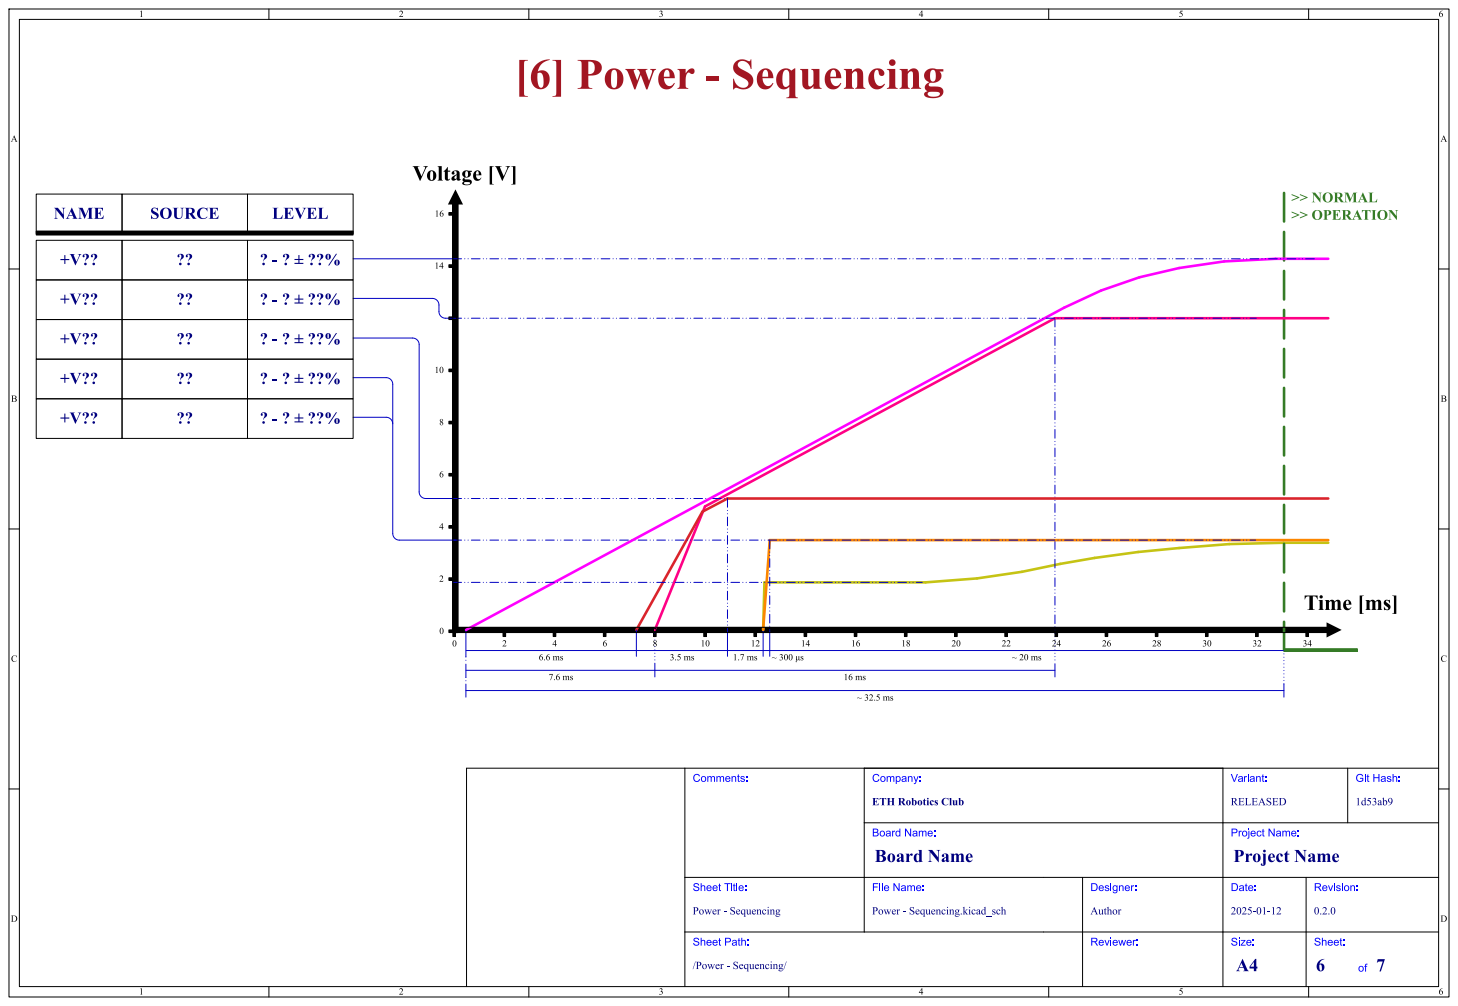
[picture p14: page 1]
Sheet: of 7; Size: A4; Revision: 0.2.0 Date: Project Name: 2025-01-12 Reviewer: Designer: Power- Sequencing.kicad_sch; Author Board Name:; Variant: RELEASED; Company: ETH RoboticsClub BoardName; ProjectName; Sheet Title:; File Name:; /Power- Sequencing/ Sheet Path: Power- Sequencing Comments:; Git Hash: 1d53ab9; NAME; >> NORMAL; >> OPERATION; Voltage[V]; Time[ms]

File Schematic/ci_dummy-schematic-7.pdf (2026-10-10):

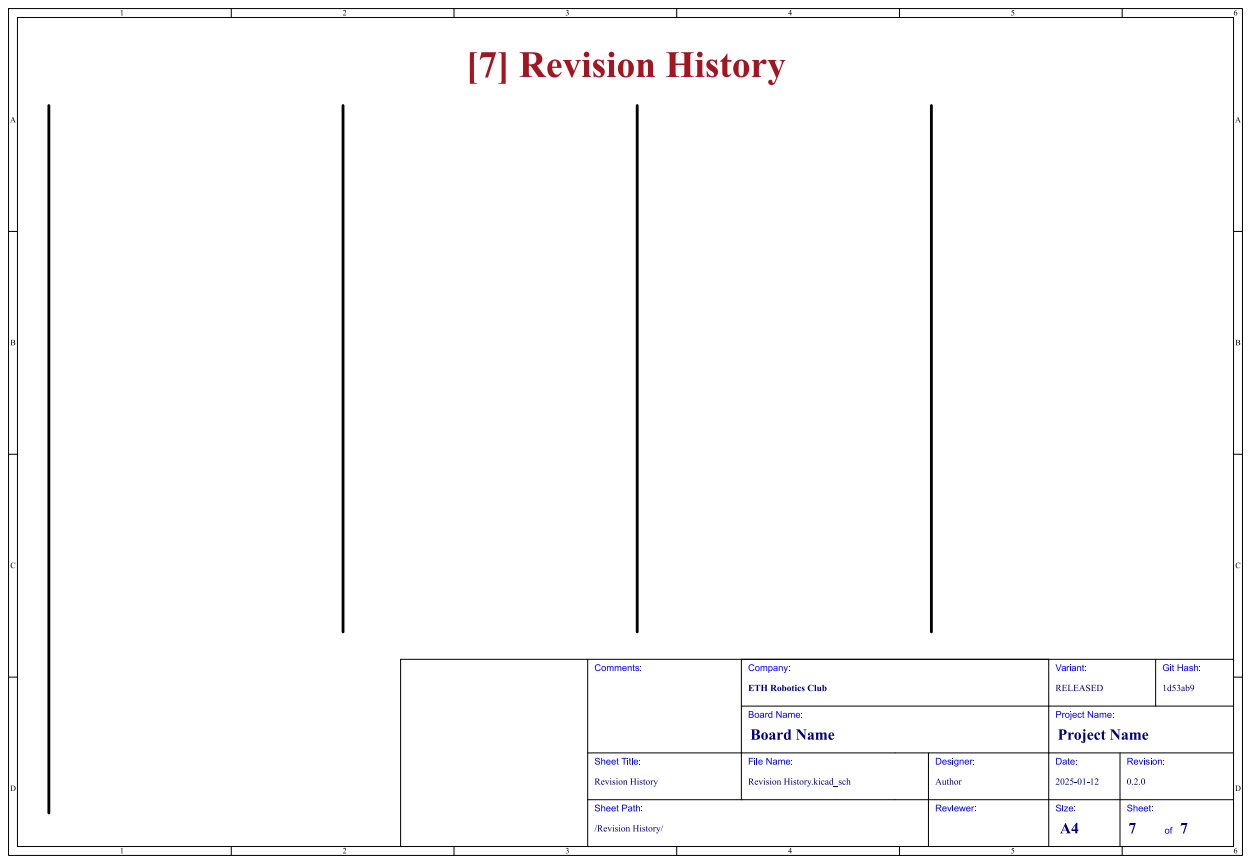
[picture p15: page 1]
Sheet: of 7; Size: A4; Revision: 0.2.0 Date: Project Name: 2025-01-12 Reviewer: Designer: RevisionHistory.kicad_sch; Author Board Name:; Variant: RELEASED; Company: ETH RoboticsClub BoardName; ProjectName; Sheet Title:; File Name:; /RevisionHistory/ Sheet Path: RevisionHistory Comments:; Git Hash: 1d53ab9 [7] RevisionHistory

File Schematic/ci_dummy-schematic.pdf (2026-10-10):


Not fitted components are marked as

DRAFT - Veryearlystageof schematic,ignoredetails.
PRELIMINARY - Closetofinal schematic.
CHECKED - Thereshouldn'tbeanymistakes.Contacttheengineerif youfindany.
RELEASED - A boardwiththisschematichasbeensenttoproduction.

Revision: 0.2.0 Date: Project Name: 2025-01-12 Reviewer: Designer:


Port Name | ??? | Port Name

BLOCK G

Port Name

/Block Diagram/ Sheet Path: Block Diagram


[3] ProjectArchitecture
File: Section B - TItle B.kicad_sch SectionA - Title A

Revision: 0.2.0 Date: Project Name: 2025-01-12 Reviewer: Designer:


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



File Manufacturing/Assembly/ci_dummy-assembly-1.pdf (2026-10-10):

# Board Name Assembly Document

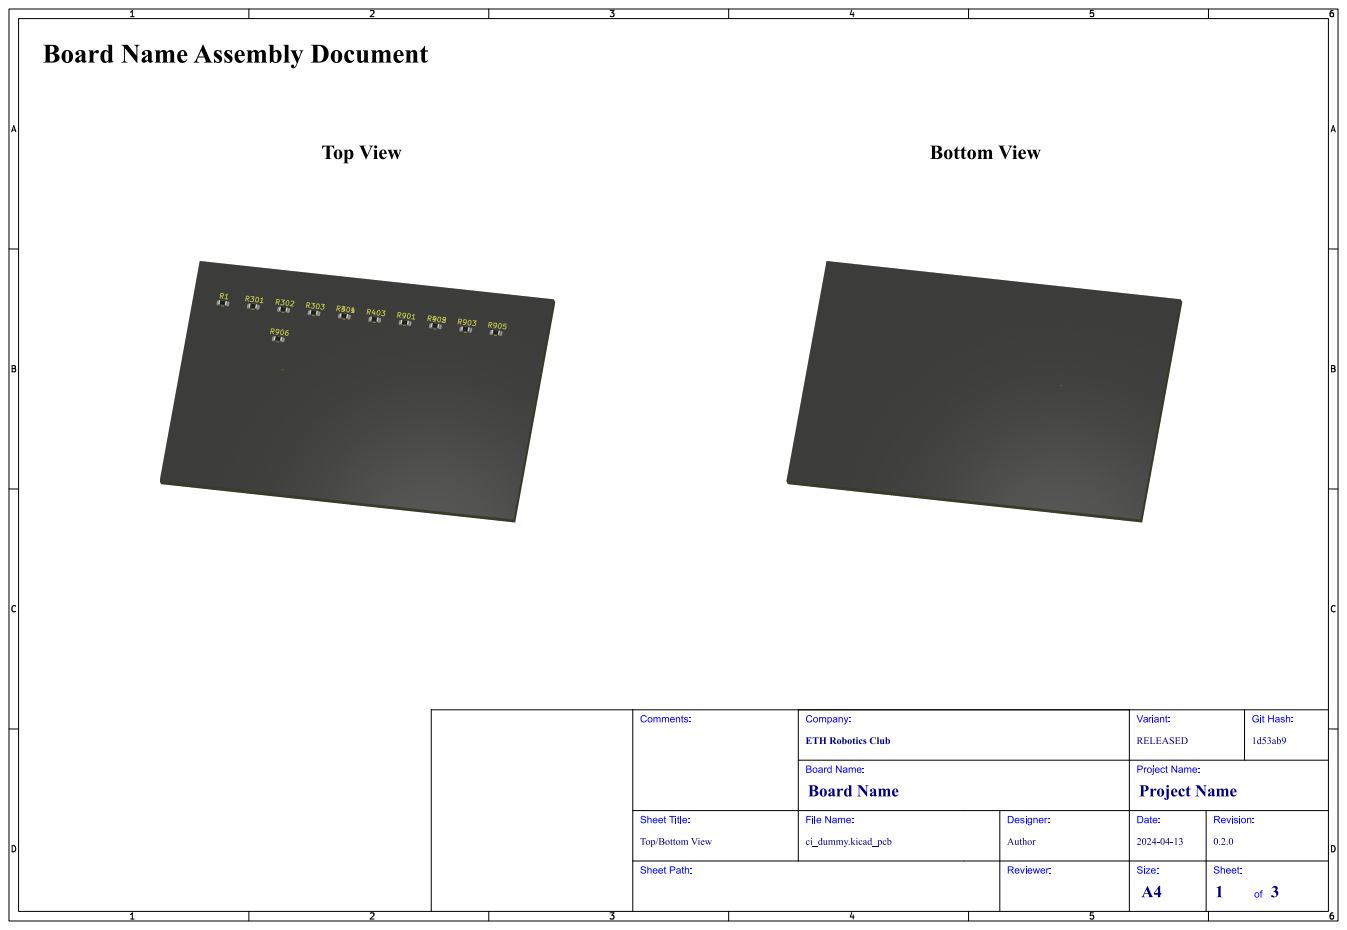
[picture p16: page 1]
Git; Hash:; Comments:; Sheet Path:; Sheet Title:; File Name:; Board Name; Project Name; Company:; RELEASED; Variant:; Board Name:; ci_dummy.kicad_pcb; Author; Designer:; Reviewer:; Project Name:; Date:; Revision:; Size:; Sheet: 1

ETH Robotics Club

Top/Bottom View

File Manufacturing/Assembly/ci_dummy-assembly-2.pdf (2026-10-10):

# Top Assembly (Scale 1:1)

# Board Name Assembly Document

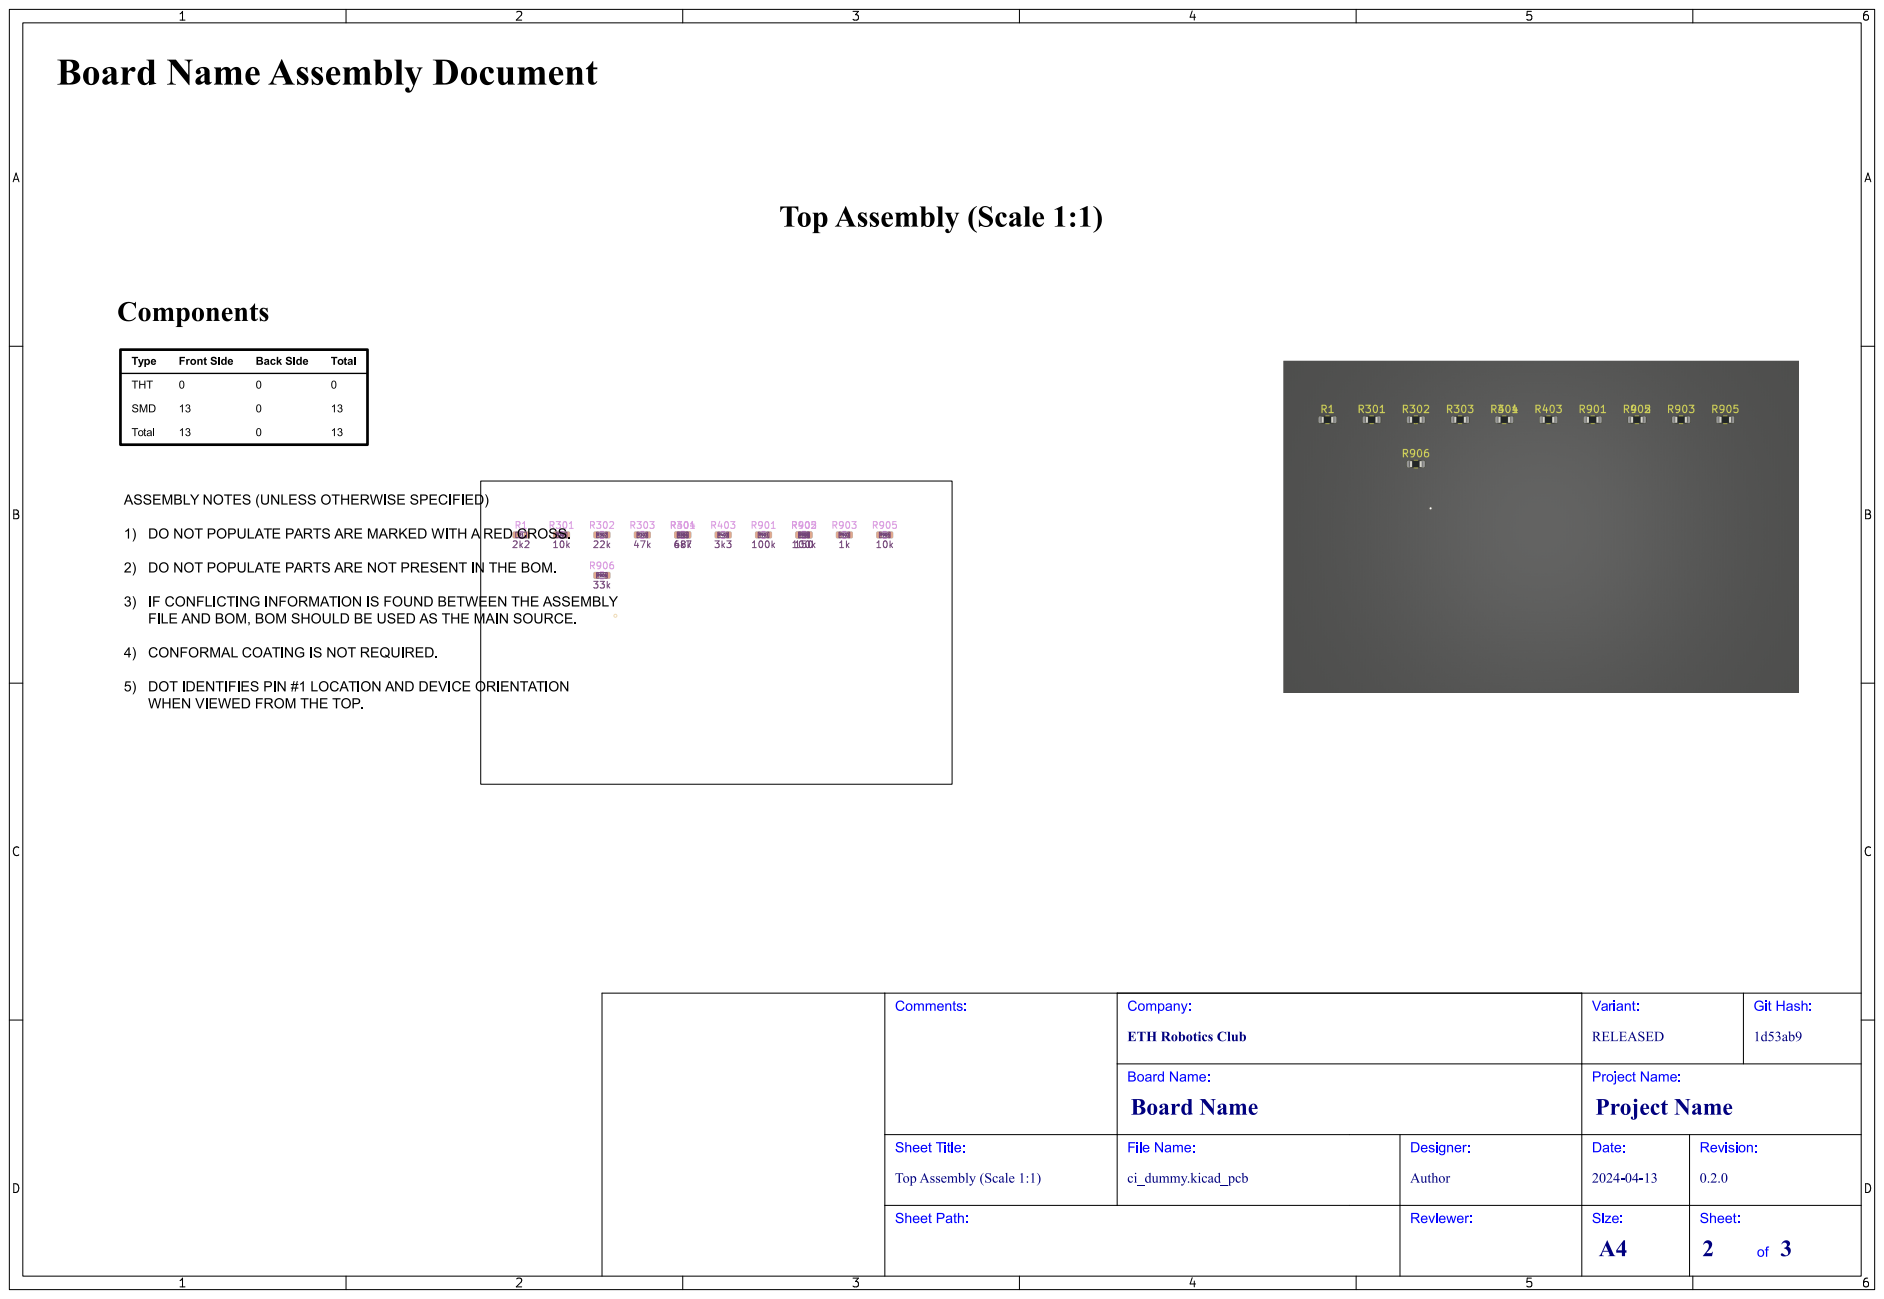
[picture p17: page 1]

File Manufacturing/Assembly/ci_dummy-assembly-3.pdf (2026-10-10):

# Bottom Assembly (Scale 1:1)

# Board Name Assembly Document

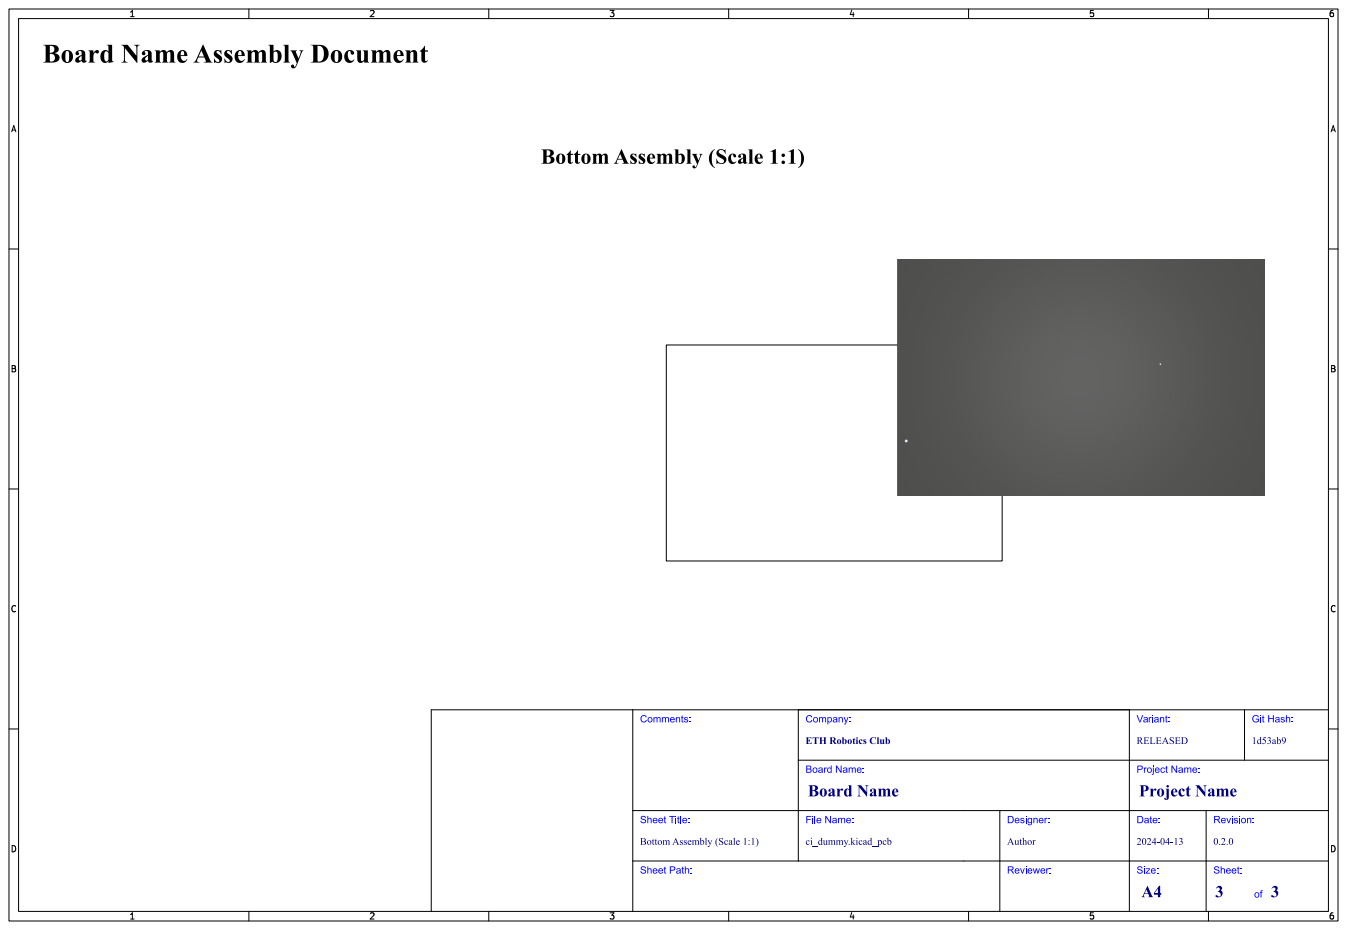
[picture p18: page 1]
Git; Hash:; Comments:; Sheet Path:; Sheet Title:; File Name:; Board Name; Project Name; Company:; RELEASED; Variant:; Board Name:; ci_dummy.kicad_pcb; Author; Designer:; Reviewer:; Project Name:; Date:; Revision:; Size:; Sheet: 3

ETH Robotics Club

Bottom Assembly (Scale 1:1)

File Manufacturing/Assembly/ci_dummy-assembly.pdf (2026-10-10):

# Board Name Assembly Document

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

ETH Robotics Club

Top/Bottom View

# Top Assembly (Scale 1:1)

# Board Name Assembly Document


# Bottom Assembly (Scale 1:1)

# Board Name Assembly Document

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

ETH Robotics Club

Bottom Assembly (Scale 1:1)

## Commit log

2026-10-09 Dummy project from template
    [Block Diagram.kicad_sch, Power - Sequencing.kicad_sch, Project Architecture.kicad_sch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]
2026-10-09 pcb: add through via (empty board breaks fab outputs)
    [ci_dummy.kicad_pcb]
2026-10-09 Update Outputs
    [ci_dummy-(L1-L6)_drill_table.csv, ci_dummy-bom.csv, ci_dummy-components_count.csv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]
2026-10-09 section-a: add R301 10k
    [Section A - Title A.kicad_sch]
2026-10-09 section-b: add R401 4k7
    [Section B - TItle B.kicad_sch]
2026-10-10 section-a: also tweak section B
    [Section B - TItle B.kicad_sch]
2026-10-10 Revert "section-a: also tweak section B"
    This reverts commit 97cee964c54efe81b466f277d38d322d4de4fe3f.
    [Section B - TItle B.kicad_sch]
2026-10-10 dev: pull-up R901
    [Project Architecture.kicad_sch]
2026-10-10 dev: pull-up R902
    [Project Architecture.kicad_sch]
2026-10-10 section-a: add R302 22k
    [Section A - Title A.kicad_sch]
2026-10-10 dev: R903 in parent
    [Project Architecture.kicad_sch]
2026-10-10 feature/section-a: add R1 (annotated entire schematic)
    [Section A - Title A.kicad_sch]
2026-10-10 feature/section-b: add R1 (annotated entire schematic)
    [Section B - TItle B.kicad_sch]
2026-10-10 dev: re-annotate duplicate R1 in Section B as R403
    [Section B - TItle B.kicad_sch]
2026-10-10 section-a: add R303 (unconnected)
    [Section A - Title A.kicad_sch]
2026-10-10 section-a: grant myself all sheets, edit B
    [Section B - TItle B.kicad_sch]
2026-10-10 Revert "section-a: grant myself all sheets, edit B"
    This reverts commit 251938f37402ec01835c63d89290224a217dfbed.
    [Section B - TItle B.kicad_sch]
2026-10-10 dev: R905
    [Project Architecture.kicad_sch]
2026-10-10 dev: no-connect flags on unconnected test resistors (ERC clean)
    [Project Architecture.kicad_sch, Section A - Title A.kicad_sch, Section B - TItle B.kicad_sch]
2026-10-10 pcb: board outline, update PCB from schematic (10 resistors)
    [ci_dummy.kicad_pcb]
2026-10-10 Update Outputs (release)
    [ci_dummy-B_Mask.gbr, ci_dummy-B_Paste.gbr, ci_dummy-B_Silkscreen.gbr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]
2026-10-10 dev: R906 after release PR
    [Project Architecture.kicad_sch]
2026-10-10 section-b: CAN termination R405
    [Section B - TItle B.kicad_sch]
2026-10-10 section-a: R304 + fragment
    [Section A - Title A.kicad_sch]
2026-10-10 dev: no-connects + footprints for R304/R405 before release
    [Section A - Title A.kicad_sch, Section B - TItle B.kicad_sch, ci_dummy.kicad_pcb]
2026-10-10 dev: no-connects for R906
    [Project Architecture.kicad_sch]
